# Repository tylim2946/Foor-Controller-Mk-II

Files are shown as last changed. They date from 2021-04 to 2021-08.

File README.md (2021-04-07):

# Foor Controller MK II

## Introduction

This device allows you to type keyboard or mouse inputs with your foot. This time, it does not require an external software (i.e. FC Options) and uses HID protocol that can be run on many different platforms.

## Preparation

1. HM-10 Bluetooth Module (Uses TI CC2541)
2. Arduino Pro Mini 3.3V
3. MPU9250 Breakout Board
4. TP4056 Battery Charger with Protection
5. 3.7V Li-Po Battery
6. USB to TTL Serial Adaptor

## Getting Started

### 1. Flashing CC2541 HID Firmware

1. Download [CCLoader.exe](https://github.com/RedBearLab/CCLoader/tree/master/Windows) and [CCLoader.ino](https://github.com/RedBearLab/CCLoader/blob/master/Arduino/CCLoader/CCLoader.ino) and upload the sketch to Arduino
2. Wire by referring to the following schematic:
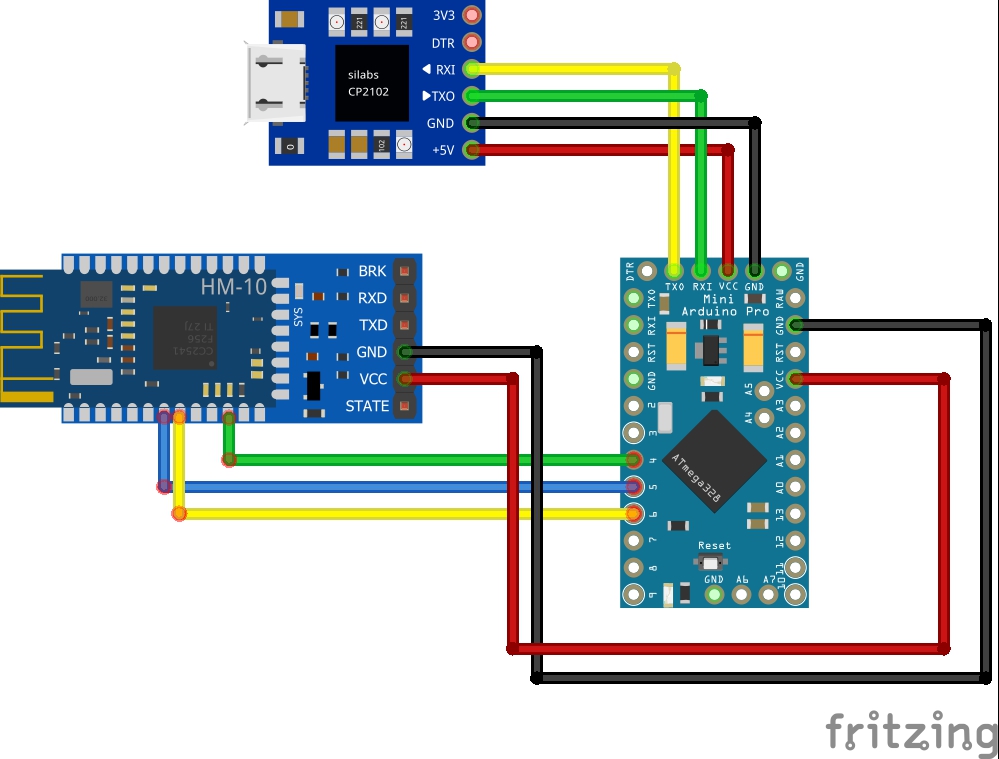
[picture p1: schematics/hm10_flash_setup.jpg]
> 
3. Download the [firmware](https://github.com/joric/cc2540-keyboard/blob/master/BLE-CC254x-1.4.0/Projects/ble/HIDEmuKbd/CC2540DB/CC2540DK-MINI%20Keyfob%20Slave/Exe/HidEmuKbd.hex) and convert .hex to .bin
4. Put CC2541 into command mode by sending "@@@" then Carriage Return at 57600 baud
5. Run CCLoader.exe, then enter the following command line: "CCLoader.exe [Port] [FileName] 0"
> i.e. COM1 and HIDEmuKbd.bin: "CCLoader.exe 1 HIDEmuKbd.bin 0"

### 2. Download Arduino program

1. Download and upload the [sketch](https://github.com/tylim2946/Foor-Controller-Mk-II/blob/main/Foot-Controller/Foot-Controller.ino) to Arduino

### 3. Soldering

1. Solder by referring to the following schematic:
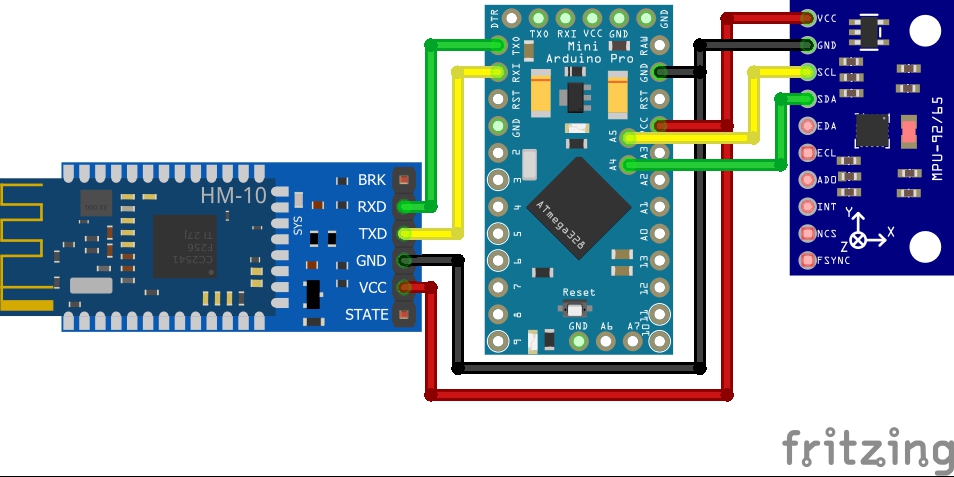
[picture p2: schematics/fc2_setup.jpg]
> 

## Images

<table>
	<tr>
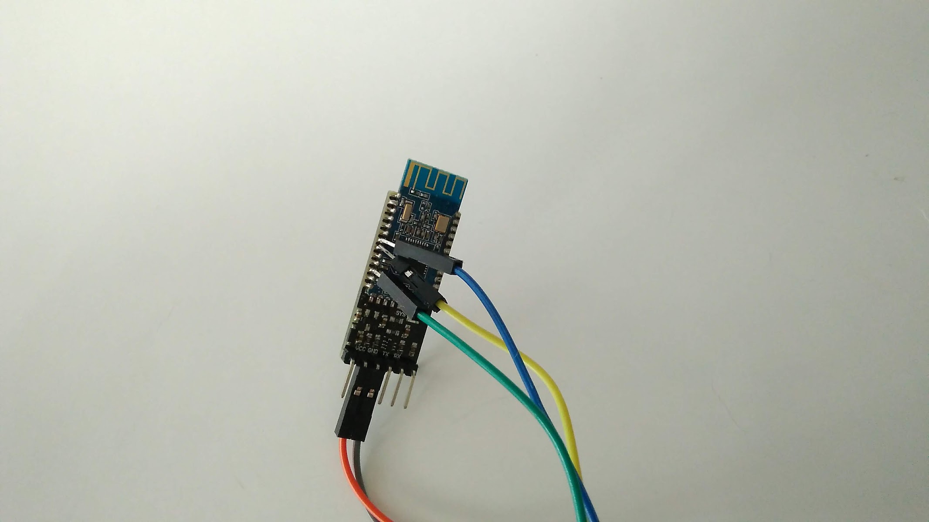
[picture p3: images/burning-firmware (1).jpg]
		<td></td>
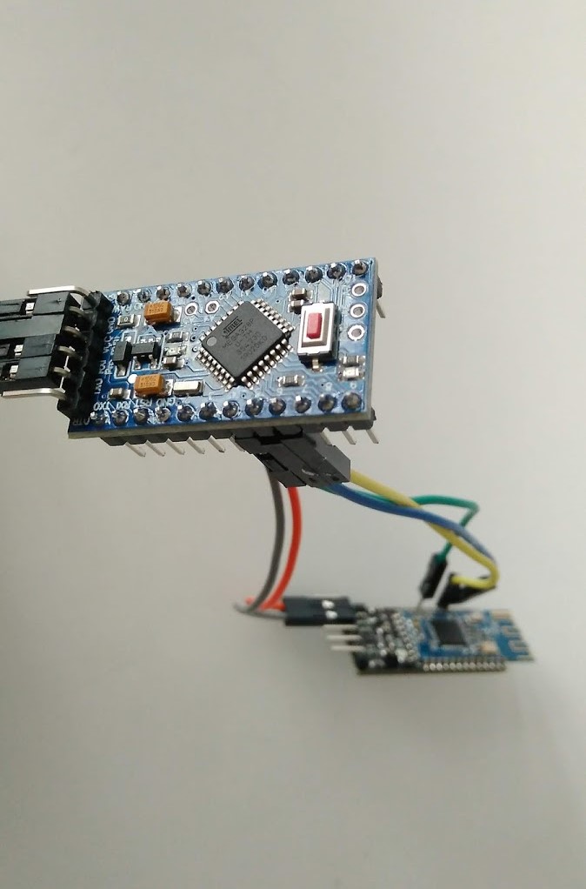
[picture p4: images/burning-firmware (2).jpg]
		<td></td>
	</tr>
</table>
<table>
	<tr>
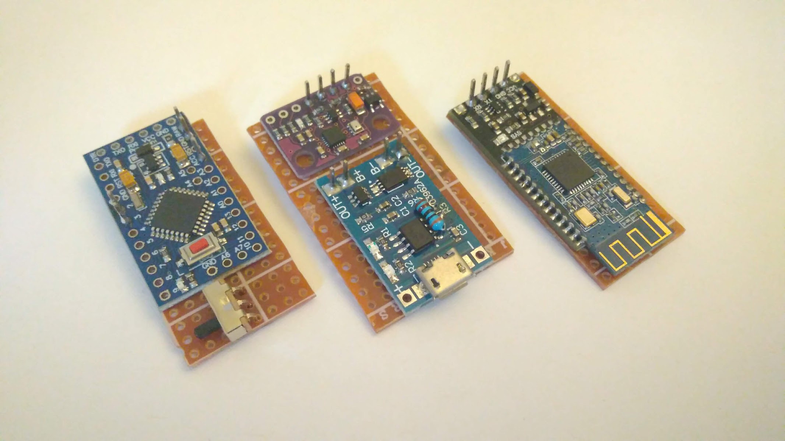
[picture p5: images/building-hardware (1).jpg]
		<td></td>
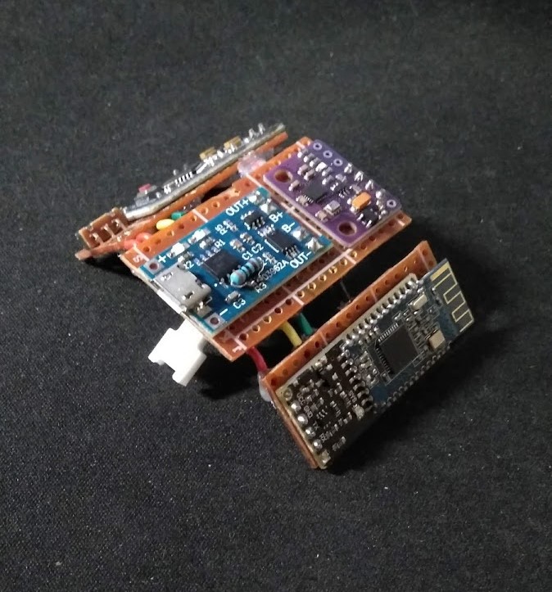
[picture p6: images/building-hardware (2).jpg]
		<td></td>
	</tr>
</table>

## Tools Used

- [CCLoader](https://github.com/RedBearLab/CCLoader)

## Firmware Used

- [HidEmuKbd](https://github.com/joric/cc2540-keyboard)

## Library Used

- [MPU9250](https://github.com/hideakitai/MPU9250)

## See Also
- [Turning HM-10, HM-11 into Bluetooth HID modules](https://imgur.com/a/KWmz6)
- [cc25xx-hidKbdM](https://github.com/rampadc/cc254x-hidKbdM)

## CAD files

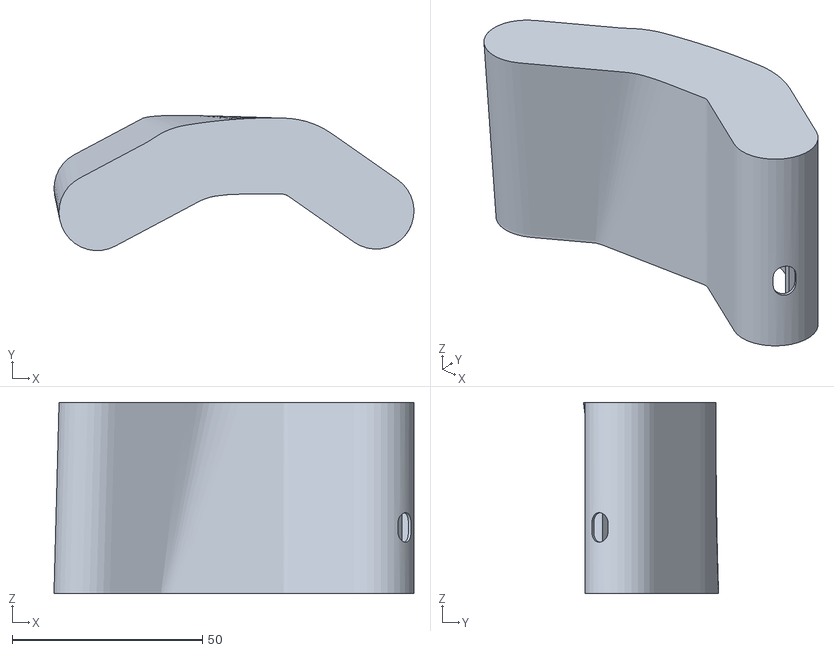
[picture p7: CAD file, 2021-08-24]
3D models/body_unfinished.stl
94.6 x 35.5 x 50.3

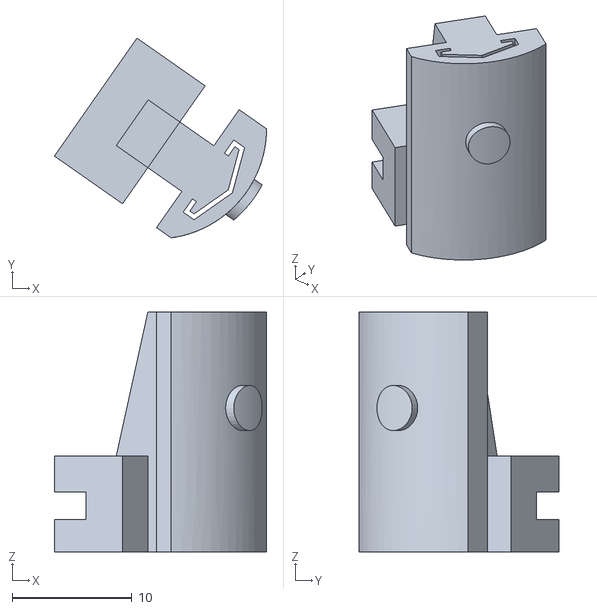
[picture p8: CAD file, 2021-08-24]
3D models/power_switch_unfinished.stl
17.7 x 16.6 x 20.0

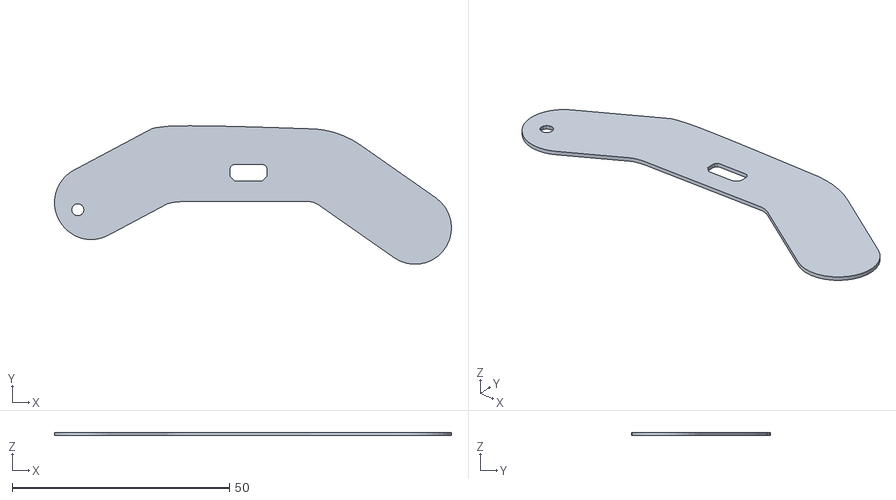
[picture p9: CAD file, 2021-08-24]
3D models/lid_unfinished.stl
91.3 x 31.9 x 0.8

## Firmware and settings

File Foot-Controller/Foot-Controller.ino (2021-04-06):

#include "MPU9250.h"
#include <SoftwareSerial.h>
#include <math.h>

MPU9250 mpu;

//this is a github version
/*
 * ToDo:
 * -upload gravity calibration.ino DONE
 * -calibrate gravity and test other functions DONE
 * -disable startup comment in mpu.update() DONE
 * -move the library to the github DONE
 * -change the angles to 0 - 360
 * -linAcc and appAcc have the same definition, remove the one that is not used
 * 
 * I should use velocity or distance instead of acceleration
 */

float maximum[3];

int packet; //number of data
int start_time = 0;
float data_rate = 0;

SoftwareSerial hid(3, 2);

void setup()
{
  Serial.begin(57600);
  Wire.begin();

  mpu.setup();
  mpu.setGravity(0.955);

  hid.begin(57600);
  hid.write("@@@"); // activate the command mode
 
  delay(2000); //ignore first few values
}

void loop()
{
  static uint32_t prev_ms = millis();
    
  if ((millis() - prev_ms) > 1) // millis() > 4200 does  not ignore the first values. Perhaps the value changes as I read it
  {
    mpu.update();

    if (Serial.available())
    {
      //mpu.setGravity(Serial.parseFloat());
    }

    if (millis() > 4200)
    {
      //record maximum
      for (int i = 0; i < 3; i ++)
      {
        if (maximum[i] < mpu.getAppAcc(i))
        {
          maximum[i] = mpu.getAppAcc(i);
        }
      }

      // measuring the data rate
      // unit: data per second
      if (start_time == 0)
      {
        start_time = millis();
      }
      
      packet ++;
      data_rate = (float)packet / (millis() - start_time);
    }
       
    Serial.print(mpu.getRoll(), 2);
    Serial.print(" ");
    Serial.print(mpu.getPitch(), 2);
    Serial.print(" ");
    Serial.print(mpu.getYaw(), 2);
    Serial.print("      ");
        
    for(int i = 0; i < 3; i ++)
    {
      Serial.print(mpu.getAcc(i), 2);
      Serial.print(" ");
    }
    
    Serial.print("      ");

    for(int i = 0; i < 3; i ++)
    {
      Serial.print(mpu.getAppAcc(i), 2);
      Serial.print(" ");
    }

    Serial.print("      ");

    for(int i = 0; i < 3; i ++)
    {
      Serial.print(maximum[i], 2);
      Serial.print(" ");
    }

    Serial.print("      ");
    Serial.print(mpu.getGravity(), 3);
    Serial.print("      ");
    Serial.print(mpu.getCalculatedGravity(), 3);
    Serial.print("      ");
    Serial.print(millis());
    Serial.print("    ");
        
    int x = round(mpu.getAppAcc(1) * 100 + 1);
    int y = round(mpu.getAppAcc(0) * 100 + 1);

    //come up with a way to define deadzone
    if (abs(x) < 5)
    {
      x = 0;
    }

    if (abs(y) < 5)
    {
      y = 0;  
    }
        
    Serial.print(x);
    Serial.print("    ");
    Serial.print(y);
    Serial.print("    ");
    Serial.print(data_rate * 1000);
    Serial.print("    ");
    Serial.print(packet);
    Serial.print("    ");
    Serial.print(start_time);
    Serial.println("");

    sendMouseReport(0, x, y, 0); //move this so that it only works approximately after 4s

    prev_ms = millis();
  }
}

void sendMouseReport (int stat, int dx, int dy, int dz)
{
  byte mouseReport[] = {(byte)stat, (byte)dx, (byte)dy, (byte)dz};
  hid.write("M");
  hid.write(mouseReport, 4);
  hid.write("\r\n");
}

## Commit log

2021-04-06 Update MPU9250.h
    - approximated and compensated gravity component in the sensor data
2021-08-24 Uploaded 3D Models
    [body_unfinished.stl, lid_unfinished.stl, power_switch_unfinished.stl]
